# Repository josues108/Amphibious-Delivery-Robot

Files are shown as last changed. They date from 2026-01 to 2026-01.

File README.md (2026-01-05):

# Amphibious-Delivery-Robot
ADR repo page
This project is provided for educational and experimental purposes.  
Feel free to adapt or build upon the design.

I have attached all the STL files needed to print this project yourself. Any common 3D printer settings work, however I would recommend to
use an increased wall strenght since the flotation devices are hallow this allows for less play. I used PLA to do all of this but would recommend at least 
PETG fillament since PLA does not do too well in water. Something I unfortunately learned...

As for the coding and BOM. Transmitter_0.py goes into an Adafruit RP2040 feather and the receiver_1.py goes into the onboard Raspberry Pico W.
Although I have attached this BOM, if interested in adapting and building upon this design, I would highly recommend moving to a sprocket and chain system
as the water and land conversion can physically wear the bot's timing belt system causing loss of tension on the belts.

Best of luck! Thanks for stopping by my Github. If any questions rise please feel free to reach out to me on LinkedIn @ www.linkedin.com/in/josuesgarcia  :)

~ Josue S. Garcia

BOM:

Receiver/ADR bot:
- 1 x Raspberry Pico W
- 2 x L298N Motor drivers
- 1 x 12V 2800 mAh rechargeable Li-ion battery 
- 1 x Junction box ABS IP65 electrical enclosure box
- 1 x Freenove breakout board for Raspberry Pico W
- 1 x LM2596S buck converter
- 2 x 5mm bore idler pulleys for 6 mm width timing belt (toothless)
- 2 x 5mm bore idler pulleys for 6 mm width timing belt (toothed)
- 2 x Aluminum timing belt pulley 20&60 teeth 5 mm bore
- 1 x 433 Mhz gmrs Antenna 
- 1 x Adafruit rfm69hcw
- 1 x premium robot tracked car chassis kit (used tracks, motors, and chassis as the refence for ADR chassis design)

Transmitter/controller:
- 1 x Adafruit RP2040 Feather
- 1 x Analog Joystick
- 1 x Lipo battery
- 1 x 433 Mhz gmrs Antenna 
- 1 x Adafruit rfm69hcw

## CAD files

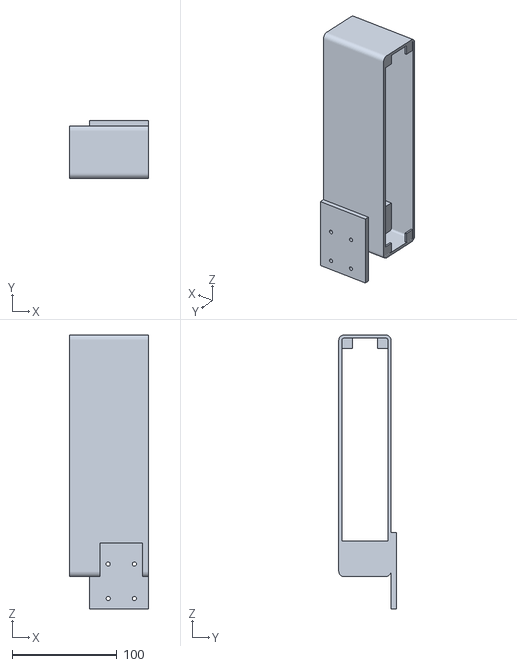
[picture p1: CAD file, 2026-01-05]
ADR_STL_files/Floatation4.stl
75.5 x 55.0 x 262.0

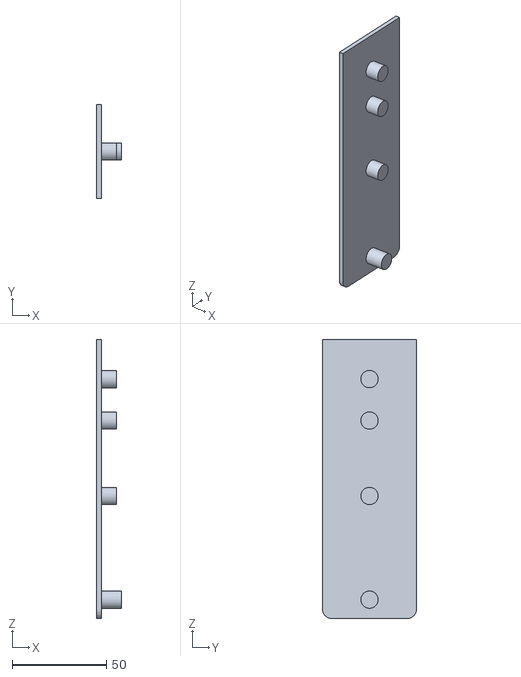
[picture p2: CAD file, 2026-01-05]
ADR_STL_files/flotation1.stl
13.0 x 50.0 x 148.0

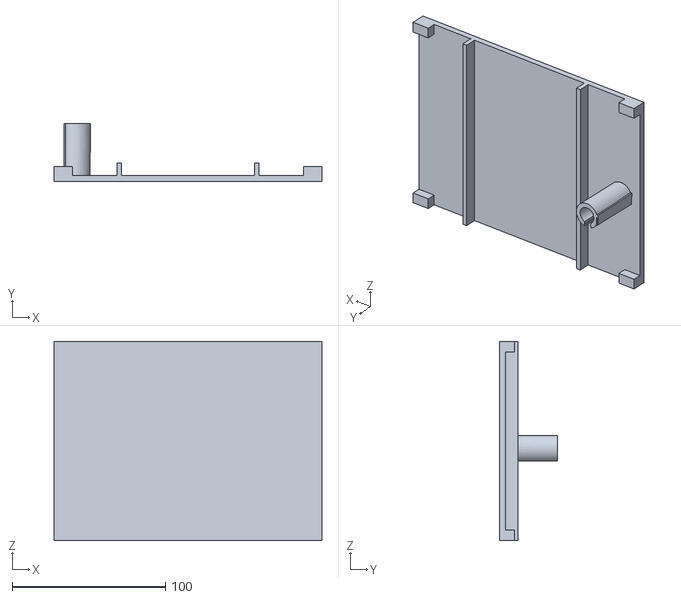
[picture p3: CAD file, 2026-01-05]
ADR_STL_files/top_flag.stl
175.0 x 38.0 x 130.0

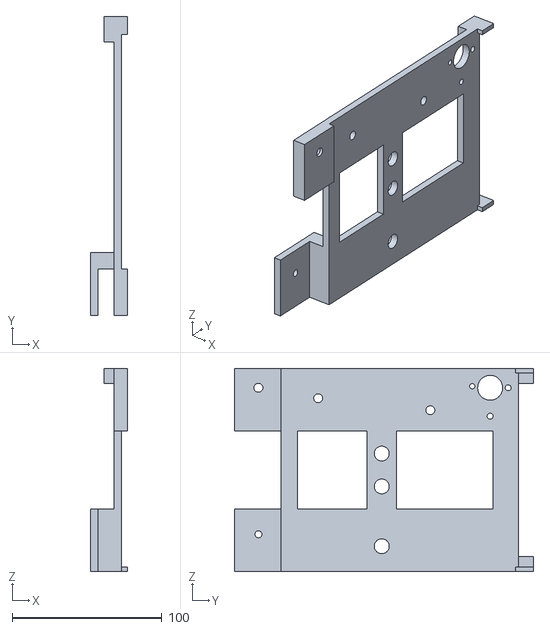
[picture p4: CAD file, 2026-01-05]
ADR_STL_files/Chassis2.stl
25.0 x 200.0 x 136.0

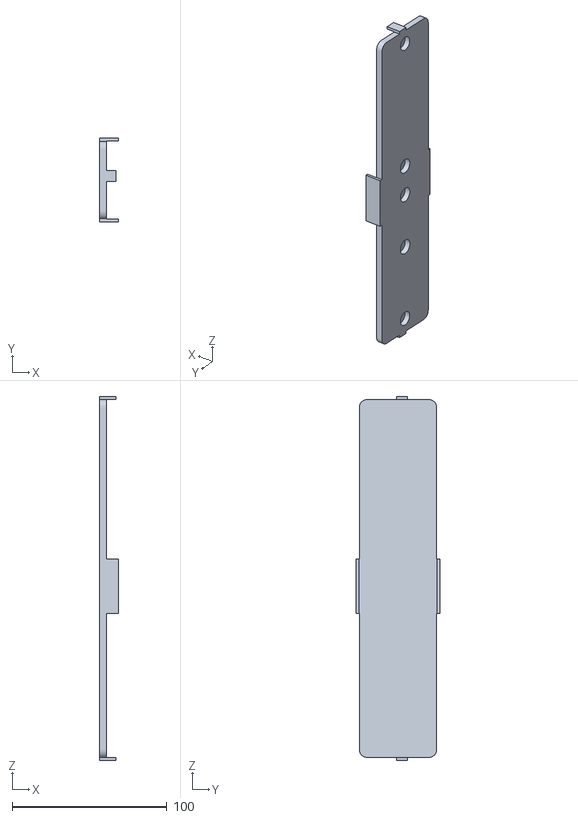
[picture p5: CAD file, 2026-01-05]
ADR_STL_files/flotation2.stl
12.0 x 54.0 x 235.0

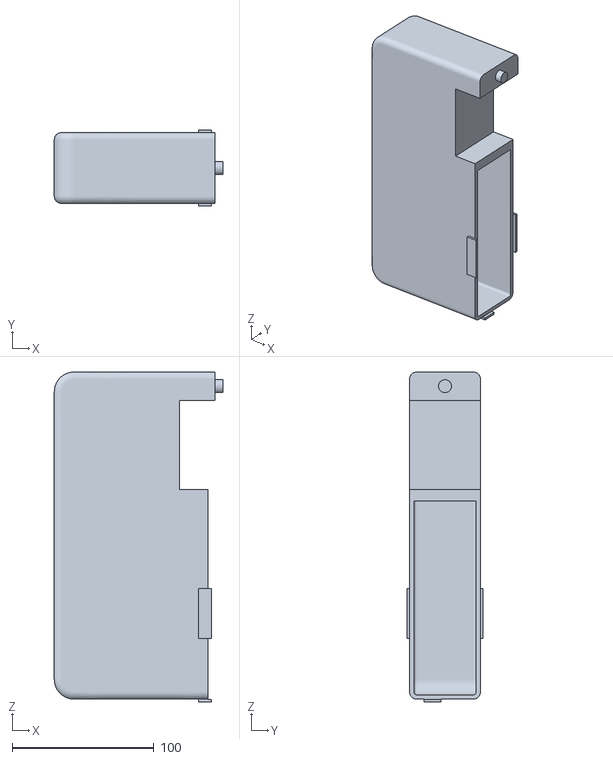
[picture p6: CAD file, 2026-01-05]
ADR_STL_files/flotation0.stl
119.0 x 54.0 x 233.0

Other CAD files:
ADR_STL_files/floatation3.stl

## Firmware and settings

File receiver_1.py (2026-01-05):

"""
This code will be the first version of the final receiver section of the project.
PICO W MUST BE FLASHED WITH CIRCUITPYTHON (Adafruit V.10.0.3)
Upload this code to the Raspberry Pico W on board the ADR Bot.


This code has a simple task: Receive (X,Y) direction vector over radio, actuate motors and movement

Something important to note is that the MAX package size is 60 bytes!!!

"""

import board
import busio
import digitalio
import time
import pwmio

import adafruit_rfm69

#Start of RFM radio set up

#Radio freq definition
RADIO_FREQ_MHZ = 433.0

#Radio pin object definition
CS = digitalio.DigitalInOut(board.GP17)
RESET = digitalio.DigitalInOut(board.GP20)

#starting SPI bus
spi = busio.SPI(board.GP18, MOSI=board.GP19, MISO=board.GP16)

# Initialze RFM radio
rfm69 = adafruit_rfm69.RFM69(spi, CS, RESET, RADIO_FREQ_MHZ)
print(f"Frequency: {rfm69.frequency_mhz}mhz")

#End of RFM radio set up


#water sensor defining
water_sensor = digitalio.DigitalInOut(board.GP28)
water_sensor.direction = digitalio.Direction.INPUT
water_sensor.pull = digitalio.Pull.DOWN


#initializing Motor control PWM GPIO object

#Left motor
land_in1 = digitalio.DigitalInOut(board.GP0)  # IN1
land_in2 = digitalio.DigitalInOut(board.GP1)  # IN2
land_in1.direction = digitalio.Direction.OUTPUT
land_in2.direction = digitalio.Direction.OUTPUT

land_enable1 = pwmio.PWMOut(board.GP2, frequency=1000, duty_cycle=0)

#Right motor
land_in3 = digitalio.DigitalInOut(board.GP3)  # IN1
land_in4 = digitalio.DigitalInOut(board.GP4)  # IN2
land_in3.direction = digitalio.Direction.OUTPUT
land_in4.direction = digitalio.Direction.OUTPUT

land_enable2 = pwmio.PWMOut(board.GP5, frequency=1000, duty_cycle=0)


#Stating the same^^ but for propellors
#Left motor
water_in5 = digitalio.DigitalInOut(board.GP6)  # IN1 for boat
water_in6 = digitalio.DigitalInOut(board.GP7)  # IN2 for boat
water_in5.direction = digitalio.Direction.OUTPUT
water_in6.direction = digitalio.Direction.OUTPUT

water_enable3 = pwmio.PWMOut(board.GP8, frequency=1000, duty_cycle=0)

#Right motor
water_in7 = digitalio.DigitalInOut(board.GP10)  # IN1 for boat
water_in8 = digitalio.DigitalInOut(board.GP11)  # IN2 for boat
water_in7.direction = digitalio.Direction.OUTPUT
water_in8.direction = digitalio.Direction.OUTPUT

water_enable4 = pwmio.PWMOut(board.GP12, frequency=1000, duty_cycle=0)

#End of motor control PWM GPIO object definition



#Defining motor control functions

#By choosing a value between 0-65535 we set speed
def land_left_motor(speed):  
    land_in1.value = True
    land_in2.value = False
    land_enable1.duty_cycle = speed

def land_right_motor(speed):
    land_in3.value = True
    land_in4.value = False
    land_enable2.duty_cycle = speed
    
def land_off():
    land_enable1.duty_cycle = 0
    land_enable2.duty_cycle = 0
    land_in1.value = False
    land_in2.value = False
    land_in3.value = False
    land_in4.value = False
    
def water_left(speed):
    water_in5.value = True
    water_in6.value = False
    water_enable3.duty_cycle = speed

def water_right(speed):
    water_in7.value = True
    water_in8.value = False
    water_enable4.duty_cycle = speed

def water_off():
    water_enable3.duty_cycle = 0
    water_enable4.duty_cycle = 0
    water_in5.value = False
    water_in6.value = False
    water_in7.value = False
    water_in8.value = False
    
#End of defining motor control functions


current_left_motor = land_left_motor
current_right_motor = land_right_motor


def decode_signed(byte_val):
    """Convert 0–255 to signed int8 (-128..127)"""
    if byte_val > 127:
        return byte_val - 256
    return byte_val

#Library of different states the motor controllers are in depending on joystick input
command_table = {
    (0,0): lambda: (current_left_motor(0), current_right_motor(0)),
    (0,1): lambda: (current_left_motor(33000), current_right_motor(33000)),
    (0,2): lambda: (current_left_motor(65535), current_right_motor(65535)),
    
    (1,0): lambda: (current_left_motor(33000), current_right_motor(0)),
    (1,1): lambda: (current_left_motor(50000), current_right_motor(33000)),
    (1,2): lambda: (current_left_motor(65535), current_right_motor(50000)),
    
    (2,0): lambda: (current_left_motor(65535), current_right_motor(0)),
    (2,1): lambda: (current_left_motor(65535), current_right_motor(33000)),
    (2,2): lambda: (current_left_motor(65535), current_right_motor(50000)),
    
    (-1,0): lambda: (current_left_motor(0), current_right_motor(33000)),
    (-1,1): lambda: (current_left_motor(33000), current_right_motor(50000)),
    (-1,2): lambda: (current_left_motor(33000), current_right_motor(65535)),
    
    (-2,0): lambda: (current_left_motor(0), current_right_motor(65535)),
    (-2,1): lambda: (current_left_motor(33000), current_right_motor(65535)),
    (-2,2): lambda: (current_left_motor(50000), current_right_motor(65535)),
}

DIRECTION = (0,0)

while True:
    #This section focuses on decoding package and spitting out easy (X,Y) form
    packet = rfm69.receive()
    

    if packet is not None and len(packet) == 2:
        x = decode_signed(packet[0])
        y = decode_signed(packet[1])
        DIRECTION = (x, y)
        print("Direction:", DIRECTION)

    elif packet is not None:
        print("Unexpected packet length:", len(packet))

    if water_sensor.value:
        # WATER MODE
        print("WATER MODE")
        land_off()
        current_left_motor = water_left
        current_right_motor = water_right
    else:
        # LAND MODE
        print("LAND MODE")
        water_off()
        current_left_motor = land_left_motor
        current_right_motor = land_right_motor
        
    command = command_table.get(DIRECTION) #(0,1) (2,0)
    command()   # execute it
            
    #print("done")
    time.sleep(0.1)

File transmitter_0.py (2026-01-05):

"""
This code will be the first version of the final transmitter section of the project.
Upload this code to the Adafruit RP20240 feather. This will be the transmitter piece.

This code has a simple task: Read joystick commands, linearize it and send it over the radio

Something important to note is that the MAX package size is 60 bytes!!!

"""

import board
import busio
import digitalio
import time
import analogio


import adafruit_rfm69

#Start of RFM radio set up

#Radio freq definition
RADIO_FREQ_MHZ = 433.0

#Radio pin object definition
CS = digitalio.DigitalInOut(board.D5)
RESET = digitalio.DigitalInOut(board.D6)

#starting SPI bus
spi = busio.SPI(board.SCK, MOSI=board.MOSI, MISO=board.MISO)

# Initializing RFM radio
rfm69 = adafruit_rfm69.RFM69(spi, CS, RESET, RADIO_FREQ_MHZ)
print(f"Frequency: {rfm69.frequency_mhz}mhz")

#End of RFM radio set up

# Defining analog objects for joystick
x_axis = analogio.AnalogIn(board.A0)
y_axis = analogio.AnalogIn(board.A1)

def read_axis(pin):
    # Convert 16-bit ADC value into a simple 0–65535
    return pin.value

def linearize(value):
    """
    Convert raw ADC (0–65535) into a signed range -2 to 2.
    Middle (~32768) becomes 0.
    """
    # convert to float range 0.0 → 1.0
    norm = value / 65535  
    
    # scale to -1.0 → +1.0
    scaled = (norm * 2.0) - 1.0
    
    # finally scale to -5 → +5
    output = scaled * 2
    
    return int(round(output))

#This is just to VISUALLY see whats being sent, can be deleted when uploaded to feather
def decode_packet(packet):
    # Unsigned values (0–255)
    unsigned = list(packet)
    # Convert to signed int8
    signed = [(b - 256) if b > 127 else b for b in unsigned]
    #print("X:", signed[0], "Y:", signed[1])

while True:
    x = read_axis(x_axis) #should be in range of 0-65535
    y = read_axis(y_axis)
    
    
    x_val = linearize(x)
    y_val = linearize(y)
    if y_val < 0:
        y_val = 0
        
    packet = bytes([x_val & 0xFF, y_val & 0xFF]) #converting integer to bytes, & 0xFF converts it into an unsigned byte
    rfm69.send(packet)
    
    decode_packet(packet)
    time.sleep(0.05)
